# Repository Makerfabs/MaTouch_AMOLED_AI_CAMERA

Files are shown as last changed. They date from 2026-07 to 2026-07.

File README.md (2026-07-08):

# MaTouch_AMOLED_AI_CAMERA

## Introduction

The "MaTouch_AMOLED_AI_CAMERA" is a high-definition integrated display, touch and vision sensing product built around the ESP32-S3 chip with built-in Wi-Fi function. It retains a high-quality 1.8-inch AMOLED screen featuring outstanding high contrast ratio and rich color saturation, delivering ultra-clear, vivid and delicate display effects for diverse visual interaction scenarios. Equipped with the professional CTS820 touch chip, it achieves more sensitive, accurate and stable touch response, effectively optimizing daily operation and human-computer interaction experience. Furthermore, the product integrates a high-performance OV3660 CMOS camera module with 3-megapixel high resolution, supporting multiple image output formats and automatic image optimization functions including automatic exposure control and automatic white balance. With excellent low-light imaging performance and high pixel fidelity, it enables clear and stable image capture, visual recognition and AI vision analysis, greatly expanding the product’s application boundaries in embedded vision, intelligent monitoring, interactive shooting and AI scenario development.

Product Link: [MaTouch_AMOLED_AI_CAMERA]

Wiki Link: [MaTouch_AMOLED_AI_CAMERA](https://wiki.makerfabs.com/MaTouch_AMOLED_AI_CAMERA.html)

Example：1.[Display_Touch_Camera_Test](https://wiki.makerfabs.com/MaTouch_AMOLED_AI_CAMERA.html#41-display_touch_camera_test)

2.[Cat_face_detection](https://wiki.makerfabs.com/MaTouch_AMOLED_AI_CAMERA.html#51-cat_face_detection)

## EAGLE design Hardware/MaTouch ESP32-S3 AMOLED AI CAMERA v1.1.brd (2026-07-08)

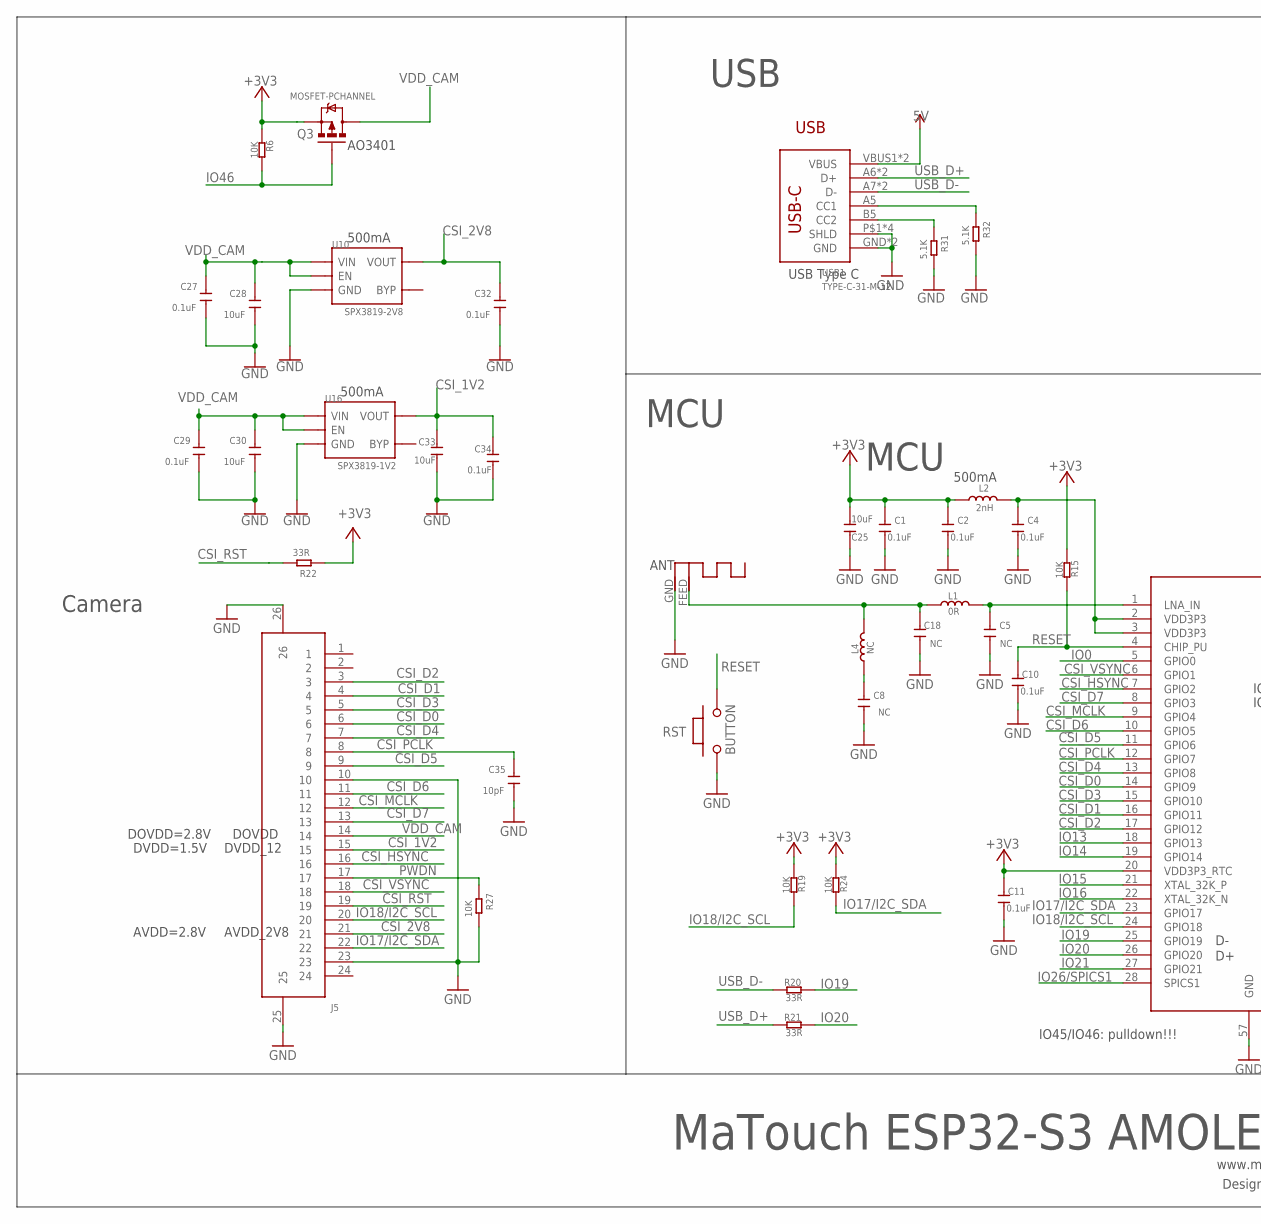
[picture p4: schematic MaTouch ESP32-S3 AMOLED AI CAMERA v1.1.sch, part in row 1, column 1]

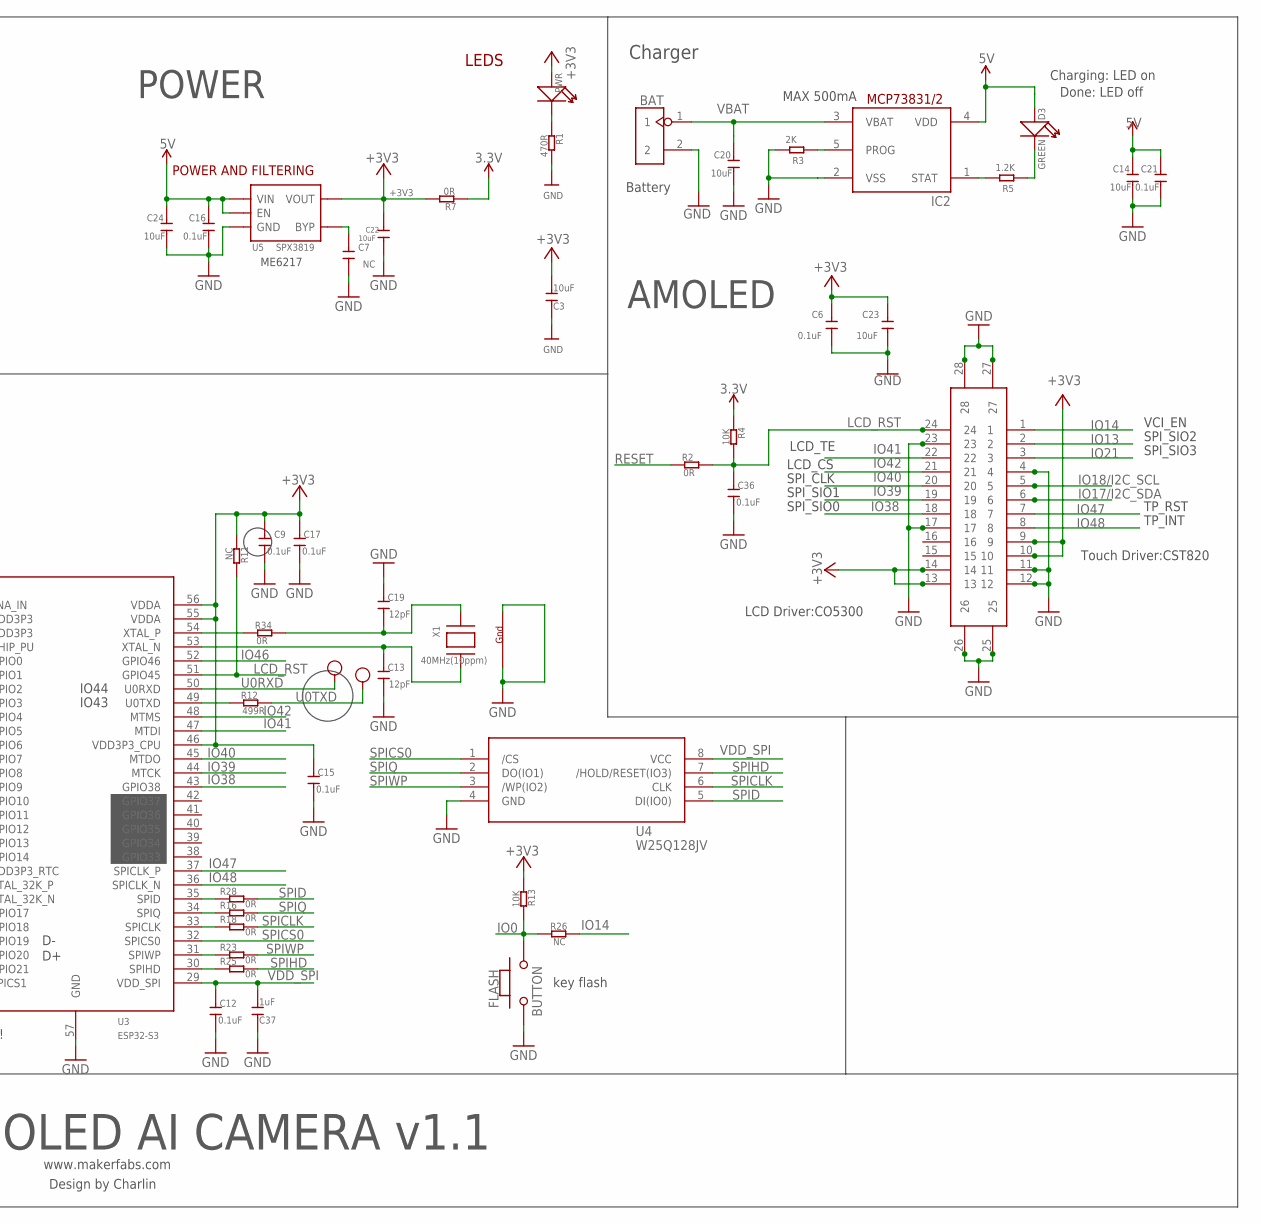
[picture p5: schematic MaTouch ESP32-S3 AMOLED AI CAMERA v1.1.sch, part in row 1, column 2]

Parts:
ANT1: ANTENNA; RN-ANT
BAT: HEADER-2P-2.0; 2P-2.0
C1, C2, C4, C6, C9, C10, C11, C12, C15, C16, C17, C21, C27, C29, C32, C34, C36: 0.1uF; DISCRETE_C0402
C3, C25: 10uF; DISCRETE_C0603
C5, C7, C8, C18: NC; DISCRETE_C0402
C13, C19: 12pF; DISCRETE_C0402
C14, C20, C23, C24, C28, C30, C33: 10uF; DISCRETE_C0402
C22: 10uF; 0603
C35: 10pF; DISCRETE_C0402
C37: 1uF; DISCRETE_C0603
D3: GREEN; DISCRETE_LED-0603
FLASH: BUTTON; 157SW
IC2: TP4054; SOT23-5L
J1: OK-14GF024-04/AXE524127; SMD24-50P-730L250W77H
J5: FPC-24P; SMD26-50P-1760L450W
L1: 0R; DISCRETE_L0402
L2: 2nH; DISCRETE_L0603
L4: NC; DISCRETE_L0402
PWR: DISCRETE_LED0603; DISCRETE_LED-0603
Q3: MOSFET-PCHANNEL; SOT23-3
R1: 470R; DISCRETE_R0402
R2, R7, R16, R18, R23, R25, R28, R34: 0R; DISCRETE_R0402
R3: 2K; DISCRETE_R0402
R4, R6, R13, R15, R19, R24, R27: 10K; DISCRETE_R0402
R5: 1.2K; DISCRETE_R0402
R11, R26: NC; DISCRETE_R0402
R12: 499R; DISCRETE_R0402
R20, R21, R22: 33R; DISCRETE_R0402
R31, R32: 5.1K; DISCRETE_R0402
RST: BUTTON; 157SW
RX: TEST-POINT'4545'; TP-D45MIL; PARTNO DNP
TX: TEST-POINT'4545'; TP-D45MIL; PARTNO DNP
U3: ESP32-S3; QFN56-7*7MM
U4: W25Q128JV; SOIC-8-208MIL
U5: SPX3819; SOT23-5
U10: SPX3819-2V8; SOT23-5
U16: SPX3819-1V2; SOT23-5
USB1: TYPE-C-31-M-12
X1: 40MHz(10ppm); NX3225

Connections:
3.3V: R4.2, R7.2
5V: C14.2, C16.2, C21.2, C24.2, D3.+, IC2.4 (VDD), U5.1 (VIN), U5.3 (EN), USB1.VBUS1 (VBUS), USB1.VBUS2 (VBUS)
+3V3: C1.2, C2.2, C3.2, C6.2, C9.2, C11.2, C15.2, C17.2, C22.1, C23.2, C25.2, J1.9, J1.10, J1.13, J1.14, L2.1, PWR.+, Q3.2 (S), R6.2, R7.1, R11.2, R13.2, R15.2, R19.2, R22.1, R24.2, U3.20 (VDD3P3_RTC), U3.46 (VDD3P3_CPU), U3.55 (VDDA), U3.56 (VDDA), U5.5 (VOUT)
CSI_1V2: C33.2, C34.2, J5.15, U16.5 (VOUT)
CSI_2V8: C32.2, J5.21, U10.5 (VOUT)
CSI_D0: J5.6, U3.14 (GPIO9)
CSI_D1: J5.4, U3.16 (GPIO11)
CSI_D2: J5.3, U3.17 (GPIO12)
CSI_D3: J5.5, U3.15 (GPIO10)
CSI_D4: J5.7, U3.13 (GPIO8)
CSI_D5: J5.9, U3.11 (GPIO6)
CSI_D6: J5.11, U3.10 (GPIO5)
CSI_D7: J5.13, U3.8 (GPIO3)
CSI_HSYNC: J5.16, U3.7 (GPIO2)
CSI_MCLK: J5.12, U3.9 (GPIO4)
CSI_PCLK: C35.2, J5.8, U3.12 (GPIO7)
CSI_RST: J5.19, R22.2
CSI_VSYNC: J5.18, U3.6 (GPIO1)
GND: ANT1.GND, BAT.2, C1.1, C2.1, C3.1, C4.1, C5.1, C6.1, C7.1, C8.1, C9.1, C10.1, C11.1, C12.1, C13.1, C14.1, C15.1, C16.1, C17.1, C18.1, C19.2, C20.1, C21.1, C22.2, C23.1, C24.1, C25.1, C27.1, C28.1, C29.1, C30.1, C32.1, C33.1, C34.1, C35.1, C36.1, C37.1, FLASH.1, IC2.2 (VSS), J1.4, J1.11, J1.12, J1.17, J1.23, J1.25, J1.26, J1.27, J1.28, J5.10, J5.23, J5.25, J5.26, R1.1, R3.2, R27.2, R31.2, R32.2, RST.1, U3.57 (GND), U4.4 (GND), U5.2 (GND), U10.2 (GND), U16.2 (GND), USB1.GND, USB1.GND2 (GND), USB1.P$1 (SHLD), USB1.P$2 (SHLD), USB1.P$3 (SHLD), USB1.P$4 (SHLD), X1.2 (G2), X1.4 (G1)
IO0: FLASH.2, R13.1, R26.2, U3.5 (GPIO0)
IO13: J1.2, U3.18 (GPIO13)
IO14: J1.1, R26.1, U3.19 (GPIO14)
IO15: U3.21 (XTAL_32K_P)
IO16: U3.22 (XTAL_32K_N)
IO17/I2C_SDA: J1.6, J5.22, R24.1, U3.23 (GPIO17)
IO18/I2C_SCL: J1.5, J5.20, R19.1, U3.24 (GPIO18)
IO19: R20.1, U3.25 (GPIO19)
IO20: R21.1, U3.26 (GPIO20)
IO21: J1.3, U3.27 (GPIO21)
IO26/SPICS1: U3.28 (SPICS1)
IO38: J1.18, U3.43 (GPIO38)
IO39: J1.19, U3.44 (MTCK)
IO40: J1.20, U3.45 (MTDO)
IO41: J1.22, U3.47 (MTDI)
IO42: J1.21, U3.48 (MTMS)
IO46: Q3.1 (G), R6.1, U3.52 (GPIO46)
IO47: J1.7, U3.37 (SPICLK_P)
IO48: J1.8, U3.36 (SPICLK_N)
LCD_RST: C36.2, J1.24, R2.1, R4.1, R11.1, U3.51 (GPIO45)
unnamed: ANT1.FEED, C18.2, L1.1, L4.2
unnamed: C5.2, L1.2, U3.1 (LNA_IN)
unnamed: R28.2, U3.35 (SPID)
unnamed: C8.2, L4.1
unnamed: R32.1, USB1.A5 (CC1)
unnamed: PWR.-, R1.2
unnamed: IC2.5 (PROG), R3.1
unnamed: IC2.1 (STAT), R5.2
unnamed: D3.-, R5.1
unnamed: C4.2, L2.2, U3.2 (VDD3P3), U3.3 (VDD3P3)
unnamed: R31.1, USB1.B5 (CC2)
unnamed: R16.2, U3.34 (SPIQ)
unnamed: R34.2, U3.54 (XTAL_P)
unnamed: R18.2, U3.33 (SPICLK)
unnamed: R23.2, U3.31 (SPIWP)
unnamed: R25.2, U3.30 (SPIHD)
unnamed: R12.2, U3.49 (U0TXD)
unnamed: C13.2, U3.53 (XTAL_N), X1.3 (X2)
unnamed: C19.1, R34.1, X1.1 (X1)
unnamed: C7.2, U5.4 (BYP)
PWDN: J5.17, R27.1
RESET: C10.2, R2.2, R15.1, RST.2, U3.4 (CHIP_PU)
SPICLK: R18.1, U4.6 (CLK)
SPICS0: U3.32 (SPICS0), U4.1 (/CS)
SPID: R28.1, U4.5 (DI(IO0))
SPIHD: R25.1, U4.7 (/HOLD/RESET(IO3))
SPIQ: R16.1, U4.2 (DO(IO1))
SPIWP: R23.1, U4.3 (/WP(IO2))
U0RXD: RX.T, U3.50 (U0RXD)
U0TXD: R12.1, TX.T
USB_D+: R21.2, USB1.A6 (D+), USB1.B6 (D+)
USB_D-: R20.2, USB1.A7 (D-), USB1.B7 (D-)
VBAT: BAT.1, C20.2, IC2.3 (VBAT)
VDD_CAM: C27.2, C28.2, C29.2, C30.2, J5.14, Q3.3 (D), U10.1 (VIN), U10.3 (EN), U16.1 (VIN), U16.3 (EN)
VDD_SPI: C12.2, C37.2, U3.29 (VDD_SPI), U4.8 (VCC)

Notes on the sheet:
www.makerfabs.com
Design by Charlin
LEDS
POWER AND FILTERING
key flash
MaTouch ESP32-S3 AMOLED AI CAMERA v1.1
POWER
MCU
ME6217
500mA
IO45/IO46: pulldown!!!
IO43
IO44
ANT
USB
AMOLED
DVDD=1.5V
AVDD=2.8V
DOVDD=2.8V
Camera
AVDD_2V8
DVDD_12
DOVDD
USB Type C
Battery
Charging: LED on
Done: LED off
Charger
MAX 500mA
AO3401
LCD_TE
LCD_CS
SPI_CLK
SPI_SIO1
SPI_SIO0
TP_INT
TP_RST
SPI_SIO3
SPI_SIO2
VCI_EN

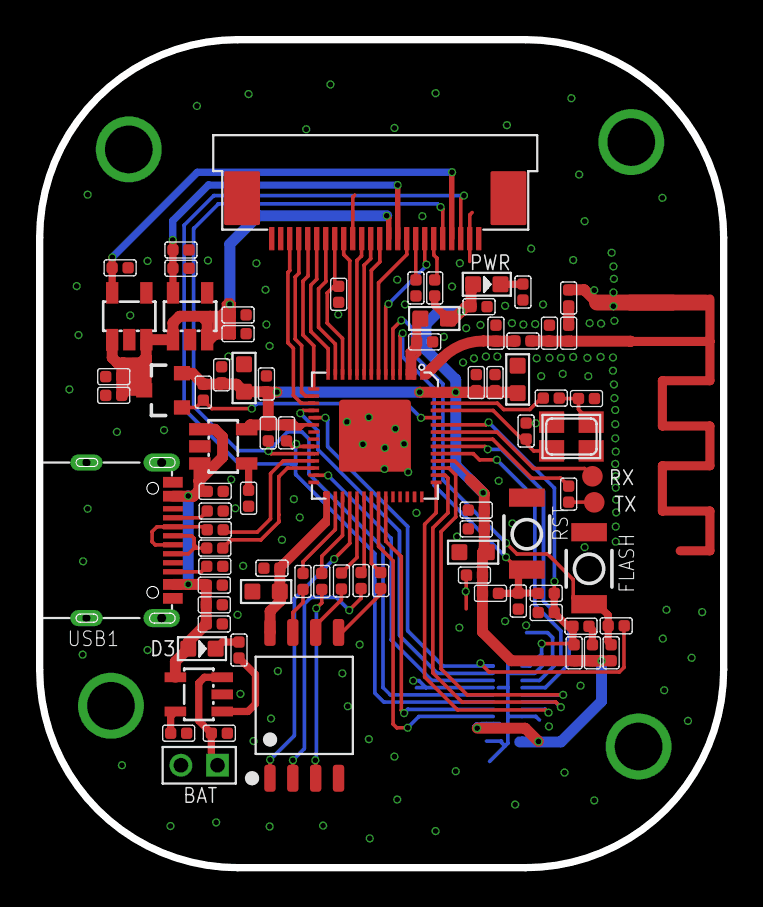
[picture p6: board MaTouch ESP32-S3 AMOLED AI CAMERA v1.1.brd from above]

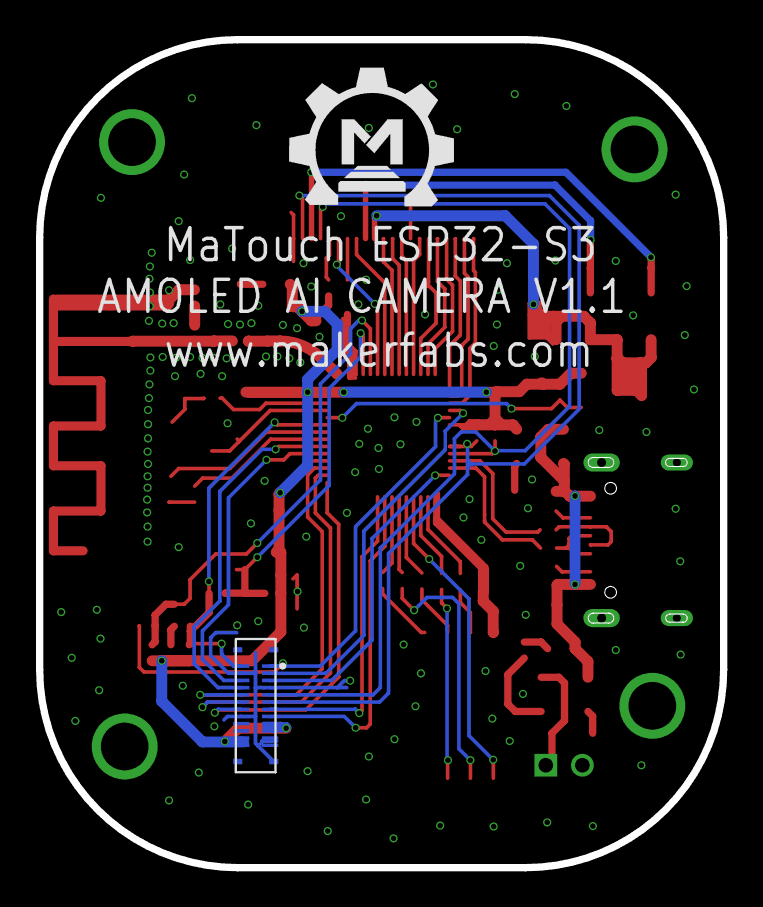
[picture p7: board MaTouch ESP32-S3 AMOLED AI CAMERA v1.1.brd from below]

Board: 2 copper layers, 38.0 x 46.0 mm, 84 parts (2 on the bottom side), 71 nets.

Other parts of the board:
U$1: MAKERFABS_0.3

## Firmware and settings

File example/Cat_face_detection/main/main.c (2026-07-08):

#include "camera_lcd_app.h"

#include "freertos/FreeRTOS.h"
#include "freertos/task.h"

#define CAMERA_APP_TASK_STACK_SIZE 16384
#define CAMERA_APP_TASK_PRIORITY   5

static void camera_app_task(void *arg)
{
    camera_lcd_app_start();
    vTaskDelete(NULL);
}

void app_main(void)
{
    xTaskCreate(camera_app_task,
                "camera_app",
                CAMERA_APP_TASK_STACK_SIZE,
                NULL,
                CAMERA_APP_TASK_PRIORITY,
                NULL);
}

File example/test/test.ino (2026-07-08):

/*
Library version:
Arduino IDE 2.3.6
esp32 V3.1.0
GFX Library for Arduino v1.5.6

Tools:
Flash size: 16MB(128Mb)
Partition Schrme: 16M Flash(3MB APP/9.9MB FATFS)
USB CDC On Boot  Enabled
PSRAM: OPI PSRAM
*/

#include <Arduino.h>
#include "camera_drv.h"
#include "display_drv.h"
#include "preview.h"
#include "touch_drv.h"

namespace
{
    enum class DemoState
    {
        TouchPage,
        CameraPreview,
        Halted
    };

    DemoState demoState = DemoState::Halted;
    bool cameraPreviewReady = false;
    bool touchWasActive = false;

    bool startCameraPreview()
    {
        if (cameraPreviewReady)
        {
            return true;
        }

        Serial.println("[MAIN] Starting camera preview");

        if (!cameraInit())
        {
            Serial.println("[MAIN] Camera init failed");
            return false;
        }

        if (!cameraPrintSensorInfo())
        {
            Serial.println("[MAIN] Sensor info failed");
            return false;
        }

        if (!cameraCaptureOnce())
        {
            Serial.println("[MAIN] Single capture failed");
            return false;
        }

        if (!previewInit())
        {
            Serial.println("[MAIN] Preview init failed");
            return false;
        }

        cameraPreviewReady = true;
        return true;
    }
}

void setup()
{
    Serial.begin(115200);
    delay(1000);
    Serial.println("Touch + Preview demo");

    if (!displayInit())
    {
        Serial.println("[MAIN] Display init failed");
        return;
    }

    displayRunFullScreenColorTest();

    if (!touchInit())
    {
        Serial.println("[MAIN] Touch init failed");
        return;
    }

    displayPrepareTouchPreviewDemo();
    Serial.println("[MAIN] Touch page ready");
    demoState = DemoState::TouchPage;
}

void loop()
{
    if (demoState == DemoState::Halted)
    {
        delay(1000);
        return;
    }

    if (demoState == DemoState::CameraPreview)
    {
        previewLoop();
        return;
    }

    TouchPoint point = {};
    if (!touchRead(point))
    {
        delay(30);
        return;
    }

    displayShowTouchPoint(point.x, point.y, point.touched);

    if (!point.touched)
    {
        touchWasActive = false;
        delay(30);
        return;
    }

    if (touchWasActive)
    {
        delay(30);
        return;
    }

    touchWasActive = true;
    Serial.printf("[MAIN] Touch x=%u y=%u\n", point.x, point.y);

    if (!displayIsPreviewButtonPressed(point.x, point.y))
    {
        delay(30);
        return;
    }

    Serial.println("[MAIN] Preview button pressed");
    if (!startCameraPreview())
    {
        Serial.println("[MAIN] Preview start failed");
        demoState = DemoState::Halted;
        return;
    }

    Serial.println("[MAIN] Camera preview running");
    demoState = DemoState::CameraPreview;
}

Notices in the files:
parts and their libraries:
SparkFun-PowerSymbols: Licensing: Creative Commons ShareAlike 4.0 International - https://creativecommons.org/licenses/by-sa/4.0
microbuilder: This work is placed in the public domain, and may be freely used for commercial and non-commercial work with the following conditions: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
